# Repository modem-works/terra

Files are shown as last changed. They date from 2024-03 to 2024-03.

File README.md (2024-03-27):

<h1 align="center">TERRA is a companion for mindful wandering</h1>

<br> <!-- Additional spacing -->
<br> <!-- Additional spacing -->

<p align="center">
  TERRA Device
</p>

<br> <!-- Additional spacing -->
<br> <!-- Additional spacing -->

##  Designed with the science of AI and the wisdom of mindfulness, TERRA is the incredible, pocket-sized compass that lets you wander without getting lost. Leave your phone behind and reconnect with your surroundings.

<br> <!-- Additional spacing -->

### Features
- **Improvised Trails, Powered by AI**: Every journey begins with a prompt. TERRA’s sophisticated AI translates your intentions, available time, and precise location into a tailored trail of GPS coordinates. Users don't know where TERRA will take them; the only certainty is finding their way back to the starting point.
- **Wander Without Your Phone**: TERRA invites users to leave their smartphones behind and reconnect with their surroundings. The standalone device boasts a minimalist interface, featuring a tranquil compass needle and gentle haptic feedback to ensure users remain engaged with the present moment.  
- **Open-Source by Design**: TERRA is designed with a DIY mindset. Anyone can download the open-source software, 3D print the CAD designs, assemble the necessary hardware, and start wandering.

<br> <!-- Additional spacing -->

<p align="center">
  ⚠️ <strong>NOTICE</strong>: This project is currently in an experimental phase and is undergoing rapid developments ⚠️
</p>

<br> <!-- Additional spacing -->

### Software

The TERRA App generates coordinates or checkpoints from a starting point and an ideal trail length using the ChatGPT API.

### Running TERRA App Locally

#### Prerequisites 
- `Node.js` v21.5
- `body-parser` v1.20.2
- `cors` v2.8.5
- `express` v4.19.0
- `node-fetch` v3.3.2

To run the TERRA App locally, follow these steps:

1. **Implement ChatGPT API Key:** Obtain a [ChatGPT API key](https://platform.openai.com/) and replace ```YOUR_OPENAI_API_KEY``` with it in the ```server.js``` file.
2. **Implement Google Maps API Key:** Obtain a [Google Places API key](https://developers.google.com/maps/documentation/places/web-service/overview) and replace ```YOUR_MAPS_KEY``` with it in the ```index.js``` file.
3. **Run Locally:** To run the application, use the command:
    ```
    node server.js
    ```
4. **Load Application:** Open `index.html` in a browser to use the app for generating a route.
5. **Download config.h File:** Download the `config.h` file which contains the generated route configuration.
6. **Update Arduino Code:** Replace the `config.h` file in the Arduino code directory with the newly downloaded file.

### Hardware

The hardware for the TERRA project is based on an ESP32 device, equipped with a range of sensors for navigation and interaction.

### Components

The main components required are:

- ESP32 Feather V2 [link](https://learn.adafruit.com/adafruit-esp32-feather-v2/pinouts)
- Waveshare 1.28" Round LCD Display Module with GC9A01 Driver [link](https://www.waveshare.com/1.28inch-lcd-module.htm)
- Adafruit Push-button Power Switch [link](https://thepihut.com/products/adafruit-push-button-power-switch-breakout)
- Beitian BN 880 GPS module [link](https://store.beitian.com/products/beitian-compass-qmc5883l-amp2-6-pix4-pixhawk-gnss-gps-glonass-dual-flight-control-gps-module-bn-880q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)
- Adafruit DRV2605L Haptic Controller Breakout [link](https://learn.adafruit.com/adafruit-drv2605-haptic-controller-breakout/arduino-code)
- CMPS12 Compass [link](https://www.robot-electronics.co.uk/cmps12-tilt-compensated-magnetic-compass.html)
- Round Battery
- USB C charging port extender

### Wiring
Connect the components together in the following order:

| ESP32 Pin | Screen | Motor Driver | Compass | GPS | Push Button |
| --- | --- | --- | --- | --- | --- |
| 3V | VCC | VIN | VIN | VIN | |
| GND | GND | GND | GND | GND | GND |
| 19 (MOSI) | DIN | | | | |
| 4 (A5) | RST | | | | |
| 5 (SCK) | CLK | | | | |
| 12 | BL | | | | |
| 15 | CS | | | | |
| 32 (A7) | | | | | OFF |
| 33 | DC | | | | |
| SDA | | SDA | SDA | | |
| SCL | | SCL | SCL | | |
| RX | | | | TX  | |
| TX | | | | RX  | |

## Arduino Code

To run the Arduino code, you will need to set up the ESP32 board and install the necessary libraries.

### Setup Steps

1. **ESP32 Arduino Setup:** Add the ESP32 board to the Arduino IDE.
    - Go to **Arduino > Preferences**.
    - Add the following URL to the **Additional Boards Manager URLs**:
      ```
      https://raw.githubusercontent.com/espressif/arduino-esp32/gh-pages/package_esp32_dev_index.json
      ```
    - Select **Adafruit Feather ESP32 V2** as the board.

2. **Install Libraries:** Install the following libraries through the Library Manager in the Arduino IDE.
    - `TinyGPSPlus.h`
    - `TFT_eSPI.h`
    - `Adafruit_DRV2605.h`

3. **Upload the Code:** After installing the libraries and updating the `config.h` file with new coordinates, upload the code to the ESP32 device. The device should work without further adjustments.

4. **Debug Mode:** A `debugMode` flag is available in the code. To test the device with manual coordinates, set this flag to `true` and input coordinates into the serial monitor.

### Further Customizations

You can use your own checkpoint files by converting black and white images into a compatible format.

#### Using Your Own Checkpoint Files

- Convert static black and white, 240x240PX `.bmp` images to `.XBM` format using [this online tool](https://www.online-utility.org/image/convert/to/XBM).
- Open the XBM file in a text editor and copy the hexadecimal values included in the curly brackets.
- Replace the existing files in the `images/checkpoints` directory with your customized `.h` file.

### Contributors
Vision + Concept: Modem<br> 
Industrial Design: Panter&Tourron<br> 
Software + Hardware: Alice Stewart<br> 
Product Renderings: Côme Lart<br> 
Illustrations: Hugo Bernier<br> 
Campaign Teaser: Michael Willis

### License
TERRA is licensed under the GNU General Public License v3.0 © 2024 Modem

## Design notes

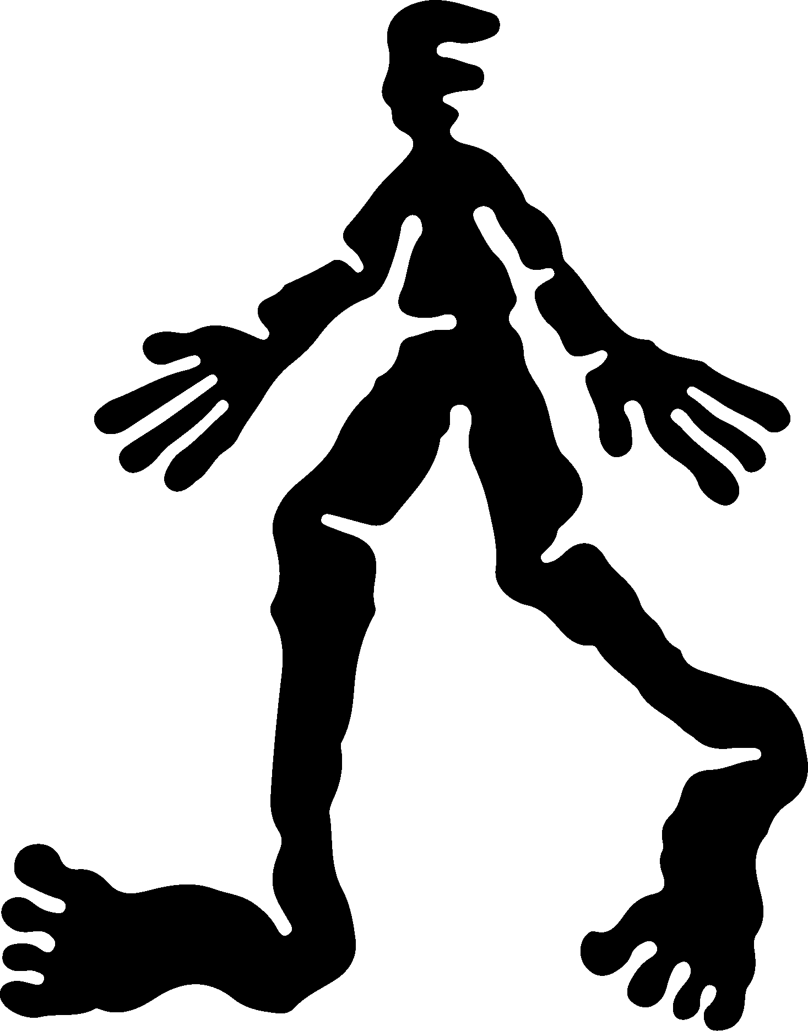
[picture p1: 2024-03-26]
App/walk.png

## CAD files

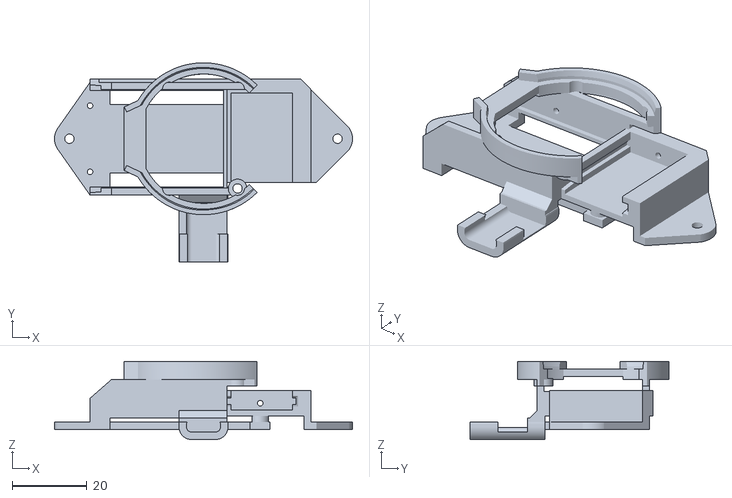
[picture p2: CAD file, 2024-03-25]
STL Files/TERRA_SKELETON_SLS_TOP.stl
80.0 x 53.5 x 21.0

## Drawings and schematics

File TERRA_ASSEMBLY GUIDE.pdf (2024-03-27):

## TERRA HARDWARE LIST

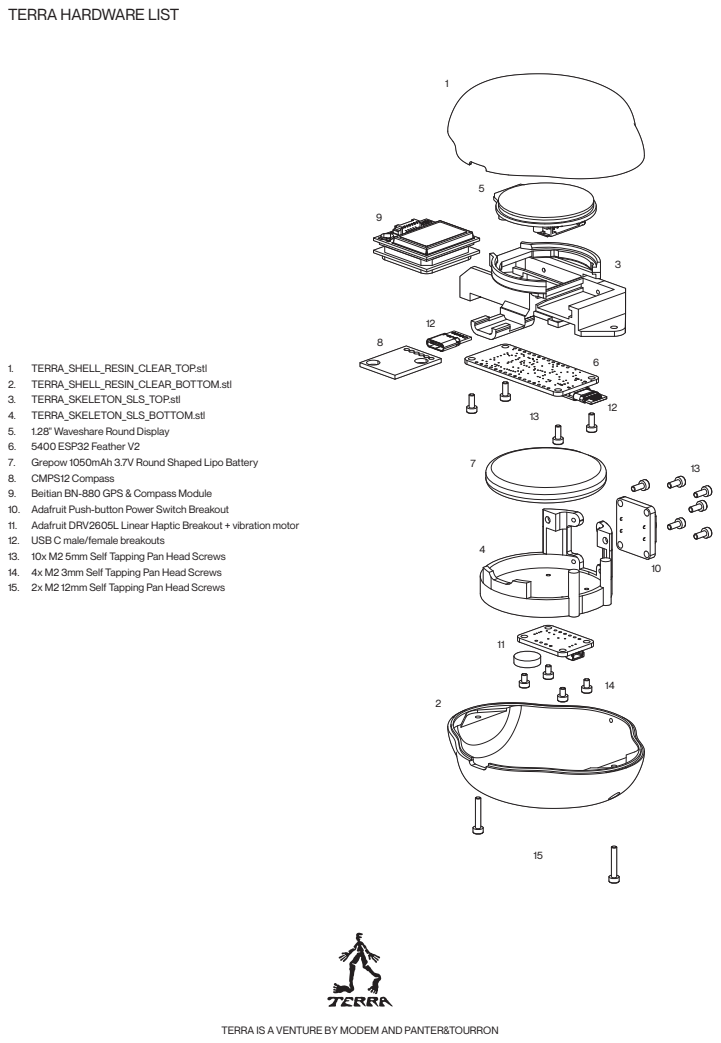
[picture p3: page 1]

1. TERRA_SHELL_RESIN_CLEAR_TOP.stl
2. TERRA_SHELL_RESIN_CLEAR_BOTTOM.stl
3. TERRA_SKELETON_SLS_TOP.stl
4. TERRA_SKELETON_SLS_BOTTOM.stl
5. 1.28" Waveshare Round Display
6. 5400 ESP32 Feather V2
7. Grepow 1050mAh 3.7V Round Shaped Lipo Battery
8. CMPS12 Compass
9. Beitian BN-880 GPS & Compass Module
10. Adafruit Push-button Power Switch Breakout
11. Adafruit DRV2605L Linear Haptic Breakout + vibration motor
12. USB C male/female breakouts
13. 10x M2 5mm Self Tapping Pan Head Screws
14. 4x M2 3mm Self Tapping Pan Head Screws
15. 2x M2 12mm Self Tapping Pan Head Screws

TERRA IS A VENTURE BY MODEM AND PANTER&TOURRON

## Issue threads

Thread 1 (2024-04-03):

Assembly Guide -> add an illustration about the wiring

mamatdunet, 2024-04-03:
Hi,

Amazing project ! Beyond the exploding view, do you plan to add a soldering / wiring illustration on the assembly guide
please (https://github.com/modem-works/terra/blob/main/TERRA_ASSEMBLY%20GUIDE.pdf) ?

https://fritzing.org/ is really good for that :).

Thank you :)

modem-works, 2024-04-05:
Hey!

Really appreciate you getting in touch and your kind feedback on the project!
Love the suggestion you shared. We’re definitely giving it some thought and will chat with our development team about it.

Best,
Fanneke

{–}

Modem
Office for Innovation and Design
@modem.works <https://instagram.com/modem.works>
modemworks.com <https://modemworks.com/>

© All rights reserved. This email and any attachments are
confidential and protected under international intellectual property
laws. If this email is not addressed to you, please delete this
email and its attachments and please be so kind to inform us.

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

mamatdunet, 2024-04-14:
Cool, thank you !

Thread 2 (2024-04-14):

Details missing from assembly guide

therealmoss, 2024-04-14:
Hello, I've been enjoying starting to build my own terra device.

Below are some details missing from the readme that I think are extremely important to add to help people get going without too much friction.

----------------------

1. **Install correct board drivers if using Mac / PC**
I was unable to connect to my Feather32 until I had installed the correct drivers [as detailed here in the Adafruit documentation. ](https://arc.net/l/quote/vlohxiwo). I think it would be wise to add this into the 'Setup steps' section of the readme.

2. **Adjust `User_Setup.h` file for TFT_eSPI library**
This one really caused me a lot of headaches. I spent many hours trying to figure out how to get the display to run _(I've only lightly dabbled in this sort of prototyping before)_!!!

3. Finally, I stumbled across [this video](https://youtu.be/k2c2zCmC_X0?si=9jiX2Kay5Wvr1BB6&t=1219), which explains how you must edit the `User_Setup.h` file in the display driver library. This finally got the display up and running for me. [Here is my own edited version of the file with the correct code changes to make the display run.](https://github.com/modem-works/terra/files/14972375/User_Setup.h.zip) Perhaps this could be included in the repo files, along with adding explicit instructions on doing this into the 'Install Libraries' step in the Arduino Code section?

3. **Add haptic motor to parts list**
You include the breakout in the parts list, but not the motor, as listed in the Assembly Guide PDF. I didn't purchase this initially, so this would be helpful to add, along with a link to an example part.

WannabeSpaceman, 2024-06-10:
I'm very glad you opened up this issue, because I'd been banging my head against a wall regarding the TFT_eSPI config issue for days now!

While the assembly instructions make sense once you've got the hardware in front of you, the setup sets could do with a lil more work

therealmoss, 2024-06-10:
I'm glad it was helpful @WannabeSpaceman !

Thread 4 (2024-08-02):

The documentation needs a demo video

Moth-6, 2024-08-02:
If anyone has built this can you share a video of the device and maybe a demo of how it works in real life?

oowze, 2024-08-04:
Looking through some of the threads on here, there seems to be a multitude of problems within the code and as of the 4th of August 2024 (5 months from it's initial release date), modem works has yet to update anything. At this point, TERRA seems to be a mere concept, I wouldn't be surprised if MW even was able to get TERRA working and in the wild.

For MW it's simply not profitable for the company to work on TERRA anymore, as a think tank modemworks has new projects to be working on and simply can't afford to spend anymore time to develop this product, there is no value in an opensource design for them. It's deflating to see such an innovative device be restricted because modemworks simply can't give a fu*k.

therealmoss, 2024-08-05:
Great idea!

therealmoss, 2024-08-22:
I'm still working on my build sporadically, but certainly no further development is happening from @modem-works

I will aim to do a demo video once I get the code working more effectively.

andrekochem, 2024-08-22:
Awesome, will love to see the further development

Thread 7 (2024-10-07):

SOS. HELP. I MUST HAVE ONE.  BLESSINS

TLALOC305, 2024-10-07:
__I have been researching this since meeting the new ram of LOVE-CAMP AT Burning Man.   I will fly wherever you are and learn how to build my own and trade you something of mine.  I will offer you and your loved ones eternal blessings and offer to be your spiritual guid in return.  René **_**_

kizeesmack, 2024-11-07:
I am currently building one and I'll let you know if its a success, its much easier in theory. theres a few hiccups that I've found!

TLALOC305, 2024-11-08:
Why don’t they sell them pre specd? Whats the  purpose if no one can’t make it Sent from my iPhoneOn Nov 7, 2024, at 2:13 AM, Kunal L. ***@***.***> wrote:
I am currently building one and I'll let you know if its a success, its much easier in theory. theres a few hiccups that I've found!

—Reply to this email directly, view it on GitHub, or unsubscribe.You are receiving this because you authored the thread.Message ID: ***@***.***>

coderolyat, 2024-11-13:
@kizeesmack hows it going I plan on making one what issues have you ran into?

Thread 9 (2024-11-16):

H

Asba3488, 2024-11-16:
11:52 O M O .
About
BBVA
App version 24.90.00
Android Operating System
8.7 K/s
Operating system version Android 14
Device model FNE-NX9 Build/HONORFNE-NO9
l33

Asba3488, 2024-11-16:
Google pay
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

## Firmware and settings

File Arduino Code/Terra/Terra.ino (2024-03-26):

// Latest working code as of March 26 2024.

bool debugMode = true;

// Include Libraries
#include <TinyGPSPlus.h>
#include <TFT_eSPI.h>
#include <Wire.h>
#include <map>
#include "Adafruit_DRV2605.h"

// Include Configurations and Images
#include "config.h"     // Assumes this contains GPS waypoints and number of stops
#include "imagelist.h"  // Assumes this includes declarations for images

// Sensor and Display Setup
#define CMPS12_ADDRESS 0x60
#define ANGLE_8 1
unsigned char high_byte, low_byte, angle8;
char pitch, roll;
unsigned int angle16;
#define BACKLIGHT_PIN 12

// TFT Display Settings
#define logoWidth 240
#define logoHeight 240
TFT_eSPI tft = TFT_eSPI();

// The TinyGPSPlus object
TinyGPSPlus gps;

// Vibration motor
Adafruit_DRV2605 drv;
int effectNumber = 58;
bool proximityVibrationTriggered = false;

// Thresholds for triggers in meters
int checkpointTrigger = 10;  // Distance from the checkpoint that is considered an arrival
int vibrationTrigger = 20;   // When to trigger vibration to indicate the checkpoint is getting close

unsigned long lastVibrationTime = 0;   // Tracks the last time vibration was triggered
int proximityVibrationDelayMs = 500;   // To determine the time between vibrations when close to the current stop.

// Image Types Enum
enum ImageType {
  NONE,
  PENDING,
  GOTOSTART,
  ARROW_N,
  ARROW_NNE,
  ARROW_NE,
  ARROW_ENE,
  ARROW_E,
  ARROW_ESE,
  ARROW_SE,
  ARROW_SSE,
  ARROW_S,
  ARROW_SSW,
  ARROW_SW,
  ARROW_WSW,
  ARROW_W,
  ARROW_WNW,
  ARROW_NW,
  ARROW_NNW,
  CHECKPOINT_1,
  CHECKPOINT_2,
  CHECKPOINT_3,
  CHECKPOINT_4,
  CHECKPOINT_5,
  CHECKPOINT_6,
  CHECKPOINT_7,
  CHECKPOINT_8,
  CHECKPOINT_9,
  CHECKPOINT_10
};
ImageType currentDisplayedImage = NONE;

enum NavigationState {
  NOT_STARTED,
  NAVIGATING,
  AT_CHECKPOINT,
  TRAIL_ENDED
};

// Initialize your navigation state
NavigationState navigationState = NOT_STARTED;  // Initial navigation state
unsigned long lastCheckpointTime = 0;           // Timestamp of when the last checkpoint was reached

// Global Variables for GPS Data and State
int currentStop = 0;
double currentLat, currentLon;
bool trailStarted = false;
bool dataReceived = false;
bool screenOn = false;
double distance;  // Distance to the next checkpoint

// Function Prototypes
void setup();
void loop();
void handleGPSData();
bool readSerialGPS();
bool readGPS();
void determineTrailStatusAndNavigate();
void processGPSData(double lat, double lon);
bool nonBlockingDelay(unsigned long ms);
void displayImage(ImageType image);
void fadeOut();
void fadeIn();
double getDistanceTo(double lat, double lon);
String getCardinalTo(double lat, double lon);
int getCourseTo(double lat, double lon);
int readCompass();

// Setup Function
void setup() {
  Serial.begin(115200);

  if (!debugMode) {
    Serial1.begin(9600);
  }

  // Screen
  tft.init();
  tft.setRotation(1);
  pinMode(BACKLIGHT_PIN, OUTPUT);
  digitalWrite(BACKLIGHT_PIN, LOW);


  // Vibration motor
  if (!drv.begin()) {
    Serial.println("Could not find DRV2605");
    while (1) delay(10);
  }

  drv.selectLibrary(1);
  // I2C trigger by sending 'go' command
  // default, internal trigger when sending GO command
  drv.setMode(DRV2605_MODE_INTTRIG);

  Wire.begin();
}

// Main Loop
void loop() {
  if (nonBlockingDelay(1000)) {
    handleGPSData();
    determineTrailStatusAndNavigate();
  }
  if (!debugMode) {
    smartDelay(1000);  // for reading the GPS module
  }
  // Continuously trigger vibration when within a certain distance of the next stop
  if (proximityVibrationTriggered && millis() - lastVibrationTime >= proximityVibrationDelayMs) {
    triggerProximityVibration();
    lastVibrationTime = millis();  // Update the last vibration time
  }
}

// This custom version of delay() ensures that the gps object is being "fed".
static void smartDelay(unsigned long ms) {
  unsigned long start = millis();
  do {
    while (Serial1.available())
      gps.encode(Serial1.read());
  } while (millis() - start < ms);
}

// Handle GPS Data
void handleGPSData() {
  if (debugMode) {  // If we're in debug mode, read the serial input
    if (Serial.available()) {
      if (readSerialGPS()) {
        dataReceived = true;  // Once the first data has arrived, we can get into our start routine
      }
    }
  } else {  // If we're not in serial input mode, start handling real GPS data
    while (Serial1.available()) {
      if (readGPS()) {
        dataReceived = true;
      }
    }
  }
}

// Read the GPS signal for current lat/lon - this is a serial input for now but can be replaced with code to read the GPS module
bool readSerialGPS() {
  String inputString = Serial.readStringUntil('\n');
  int commaIndex = inputString.indexOf(',');

  // Check if the comma exists and it's not at the end of the string
  if (commaIndex != -1 && commaIndex < inputString.length() - 1) {
    currentLat = inputString.substring(0, commaIndex).toDouble();
    currentLon = inputString.substring(commaIndex + 1).toDouble();
    return true;  // Data was successfully parsed
  } else {
    Serial.println("Invalid format. Please enter in format: lat,lon");
    return false;  // Data parsing failed
  }
}

// Read the GPS module signal for current lat/lon
bool readGPS() {
  if (gps.location.isValid()) {
    currentLat = gps.location.lat();
    currentLon = gps.location.lng();
    return true;
  }
  return false;
}

void determineTrailStatusAndNavigate() {
  static double lastDistance = -1;

  // Obtain the target coordinates based on the trail's current status
  double targetLat = !trailStarted ? startLat : stopLats[currentStop - 1];
  double targetLon = !trailStarted ? startLon : stopLons[currentStop - 1];

  // Calculate the current distance and direction to the target
  double distance = getDistanceTo(targetLat, targetLon);
  String cardinal = getCardinalTo(targetLat, targetLon);
  int targetAngle = getCourseTo(targetLat, targetLon);  // Assume implementation exists
  int currentAngle = readCompass();

  // Calculate the relative direction for navigation
  int relativeDirection = calculateRelativeDirection(currentAngle, targetAngle);

  if (navigationState == NOT_STARTED) {
    if (!dataReceived) {
      displayImage(PENDING);  // Show PENDING only when waiting for the first GPS data
    } else {
      Serial.println("Please proceed to the start of the trail.");
      displayImage(GOTOSTART);  // Now we're sure we've received data, show GOTOSTART
    }

    // Transition to navigating state once within close range to the start and data has been received
    if (dataReceived && distance <= checkpointTrigger) {
      trailStarted = true;
      currentStop = 1;
      Serial.println("Trail started. Heading to Stop 1.");
      navigationState = NAVIGATING;
    }
    return;  // Continue to skip rest of the function logic when NOT_STARTED
  }

  // Only update navigation arrow if we are in the navigating phase
  if (navigationState == NAVIGATING) {
    ImageType arrowImage = selectArrowImage(relativeDirection);
    displayImage(arrowImage);
  }

  // Start of the trail
  if (!trailStarted) {
    if (distance <= checkpointTrigger) {  // "Closeness" threshold
      trailStarted = true;
      currentStop = 1;  // Moving towards the first checkpoint
      Serial.println("Trail started. Heading to Stop 1.");
      navigationState = NAVIGATING;
    } else {
      Serial.println("Please proceed to the start of the trail.");
      if (dataReceived) {
        displayImage(GOTOSTART);  // Indicating to go to the starting point
      }
    }
  }
  // Navigating the trail
  else {
    if (distance <= checkpointTrigger && currentStop <= numberOfStops) {
      if (navigationState != AT_CHECKPOINT) {
        // Just arrived at this checkpoint
        Serial.print("Arrived at Stop ");
        Serial.println(currentStop);
        ImageType checkpointImage = static_cast<ImageType>(CHECKPOINT_1 + currentStop - 1);
        displayImage(checkpointImage);    // Show the checkpoint image
        navigationState = AT_CHECKPOINT;  // Update state to at checkpoint
        lastCheckpointTime = millis();    // Capture the time we arrived at the checkpoint

        // Check if this is the final stop
        if (currentStop == numberOfStops) {
          Serial.println("Final stop reached. Trail is complete.");
          // Display PENDING image to indicate completion
          displayImage(PENDING);
          // Optionally, you might want to change the navigation state or take other actions here
          navigationState = TRAIL_ENDED;  // Resetting the state to NOT_STARTED or another appropriate state
        }

        proximityVibrationTriggered = false;  // Allow vibration to trigger again for the next stop
        currentStop++;                        // Prepare for the next stop or complete the trail
      }
    } else if (navigationState == AT_CHECKPOINT) {
      if (millis() - lastCheckpointTime > 5000) {  // 5 seconds have passed since arriving at the checkpoint
        navigationState = NAVIGATING;              // Transition back to navigating after the delay
        proximityVibrationTriggered = false;       // Reset vibration trigger flag
      }
    } else if (navigationState == NAVIGATING && currentStop <= numberOfStops) {
      // Continue with the condition to update navigation info only if there's a significant change in distance
      if (abs(lastDistance - distance) > 0.5) {
        Serial.print("Distance to next stop: ");
        Serial.print(distance, 1);  // One decimal place for distance
        Serial.print(" meters. Direction to next stop: ");
        Serial.print(cardinal);
        Serial.print(" (Target angle: ");
        Serial.print(targetAngle);
        Serial.println(" degrees)");
        lastDistance = distance;  // Update lastDistance for next comparison

        // Here, potentially display the arrow again if needed, based on your logic for selecting and displaying arrows
        ImageType arrowImage = selectArrowImage(relativeDirection);
        displayImage(arrowImage);

        // Set the flag to start continuous vibration when within a certain distance from the next stop
        if (distance <= vibrationTrigger && !proximityVibrationTriggered) {
          proximityVibrationTriggered = true;
          lastVibrationTime = millis();  // Ensure we start timing from now
        }
      }
    }
  }
}

void triggerProximityVibration() {
  // Check if we should still be vibrating (if within a certain distance and navigating)
  if (distance <= proximityVibrationTriggered && navigationState == NAVIGATING) {
    // set the effect to play
    drv.setWaveform(0, effectNumber);  // play effect
    drv.setWaveform(1, 0);             // end waveform
    // play the effect!
    drv.go();
    // Serial.println("Vibration triggered");
    // Note: We do not set vibrationTriggered to false here as we want continuous vibration
  } else {
    // Stop vibrating if no longer within 20 meters or not in navigating state
    proximityVibrationTriggered = false;
  }
}

// Display image function - fades images out then in again
void displayImage(ImageType image) {
  if (currentDisplayedImage != image) {
    if (screenOn) {
      fadeOut();
    }
    tft.fillScreen(TFT_BLACK);  // This line is common to all cases
    switch (image) {
      case PENDING:
        drawBitmap(pending);
        Serial.println("Drawn pending.h");
        break;
      case GOTOSTART:
        drawBitmap(gotostart);
        Serial.println("Drawn gotostart.h");
        break;
      case ARROW_N:
        drawBitmap(arrow_N);
        Serial.println("Drawn arrow_N.h");
        break;
      case ARROW_NNE:
        drawBitmap(arrow_NNE);
        Serial.println("Drawn arrow_NNE.h");
        break;
      case ARROW_NE:
        drawBitmap(arrow_NE);
        Serial.println("Drawn arrow_NE.h");
        break;
      case ARROW_ENE:
        drawBitmap(arrow_ENE);
        Serial.println("Drawn arrow_ENE.h");
        break;
      case ARROW_E:
        drawBitmap(arrow_E);
        Serial.println("Drawn arrow_E.h");
        break;
      case ARROW_ESE:
        drawBitmap(arrow_ESE);
        Serial.println("Drawn arrow_ESE.h");
        break;
      case ARROW_SE:
        drawBitmap(arrow_SE);
        Serial.println("Drawn arrow_SE.h");
        break;
      case ARROW_SSE:
        drawBitmap(arrow_SSE);
        Serial.println("Drawn arrow_SSE.h");
        break;
      case ARROW_S:
        drawBitmap(arrow_S);
        Serial.println("Drawn arrow_S.h");
        break;
      case ARROW_SSW:
        drawBitmap(arrow_SSW);
        Serial.println("Drawn arrow_SSW.h");
        break;
      case ARROW_SW:
        drawBitmap(arrow_SW);
        Serial.println("Drawn arrow_SW.h");
        break;
      case ARROW_WSW:
        drawBitmap(arrow_WSW);
        Serial.println("Drawn arrow_WSW.h");
        break;
      case ARROW_W:
        drawBitmap(arrow_W);
        Serial.println("Drawn arrow_W.h");
        break;
      case ARROW_WNW:
        drawBitmap(arrow_WNW);
        Serial.println("Drawn arrow_WNW.h");
        break;
      case ARROW_NW:
        drawBitmap(arrow_NW);
        Serial.println("Drawn arrow_NW.h");
        break;
      case ARROW_NNW:
        drawBitmap(arrow_NNW);
        Serial.println("Drawn arrow_NNW.h");
        break;
      case CHECKPOINT_1:
        drawBitmap(checkpoint_1);
        Serial.println("Drawn checkpoint_1.h");
        break;
      case CHECKPOINT_2:
        drawBitmap(checkpoint_2);
        Serial.println("Drawn checkpoint_2.h");
        break;
      case CHECKPOINT_3:
        drawBitmap(checkpoint_3);
        Serial.println("Drawn checkpoint_3.h");
        break;
      case CHECKPOINT_4:
        drawBitmap(checkpoint_4);
        Serial.println("Drawn checkpoint_4.h");
        break;
      case CHECKPOINT_5:
        drawBitmap(checkpoint_5);
        Serial.println("Drawn checkpoint_5.h");
        break;
      case CHECKPOINT_6:
        drawBitmap(checkpoint_6);
        Serial.println("Drawn checkpoint_6.h");
        break;
      case CHECKPOINT_7:
        drawBitmap(checkpoint_7);
        Serial.println("Drawn checkpoint_7.h");
        break;
      case CHECKPOINT_8:
        drawBitmap(checkpoint_8);
        Serial.println("Drawn checkpoint_8.h");
        break;
      case CHECKPOINT_9:
        drawBitmap(checkpoint_9);
        Serial.println("Drawn checkpoint_9.h");
        break;
      case CHECKPOINT_10:
        drawBitmap(checkpoint_10);
        Serial.println("Drawn checkpoint_10.h");
        break;
      default:
        tft.fillScreen(TFT_BLACK);
        Serial.println("No image to display");
    }
    fadeIn();
    currentDisplayedImage = image;
  }
}

void drawBitmap(const unsigned char* bitmap) {
  tft.drawXBitmap(0, 0, bitmap, logoWidth, logoHeight, TFT_BLACK, TFT_WHITE);
}

// Example function to calculate relative direction based on angles
int calculateRelativeDirection(int currentAngle, int targetAngle) {
  int difference = targetAngle - currentAngle;
  if (difference < 0) {
    difference += 360;  // Adjust for negative differences
  }
  return difference % 360;  // Ensure the result is within 0-359 degreess
}


// Select an arrow image based on relative direction
ImageType selectArrowImage(int relativeDirection) {
  if (relativeDirection >= 348.75 || relativeDirection < 11.25) return ARROW_N;
  else if (relativeDirection >= 11.25 && relativeDirection < 33.75) return ARROW_NNE;
  else if (relativeDirection >= 33.75 && relativeDirection < 56.25) return ARROW_NE;
  else if (relativeDirection >= 56.25 && relativeDirection < 78.75) return ARROW_ENE;
  else if (relativeDirection >= 78.75 && relativeDirection < 101.25) return ARROW_E;
  else if (relativeDirection >= 101.25 && relativeDirection < 123.75) return ARROW_ESE;
  else if (relativeDirection >= 123.75 && relativeDirection < 146.25) return ARROW_SE;
  else if (relativeDirection >= 146.25 && relativeDirection < 168.75) return ARROW_SSE;
  else if (relativeDirection >= 168.75 && relativeDirection < 191.25) return ARROW_S;
  else if (relativeDirection >= 191.25 && relativeDirection < 213.75) return ARROW_SSW;
  else if (relativeDirection >= 213.75 && relativeDirection < 236.25) return ARROW_SW;
  else if (relativeDirection >= 236.25 && relativeDirection < 258.75) return ARROW_WSW;
  else if (relativeDirection >= 258.75 && relativeDirection < 281.25) return ARROW_W;
  else if (relativeDirection >= 281.25 && relativeDirection < 303.75) return ARROW_WNW;
  else if (relativeDirection >= 303.75 && relativeDirection < 326.25) return ARROW_NW;
  else if (relativeDirection >= 326.25 && relativeDirection < 348.75) return ARROW_NNW;
  else return ARROW_N;  // Default case, although logically unnecessary due to the first condition
}

// Non blocking delay to read sensors
bool nonBlockingDelay(unsigned long ms) {
  static unsigned long lastCheck = 0;
  unsigned long currentMillis = millis();
  if (currentMillis - lastCheck >= ms) {
    lastCheck = currentMillis;
    return true;
  }
  return false;
}

// Simple function to get distance to lat/lon, is used to determine whether GPS module is in range of a stop
double getDistanceTo(double lat, double lon) {
  return TinyGPSPlus::distanceBetween(currentLat, currentLon, lat, lon);
}

String getCardinalTo(double lat, double lon) {
  double courseTo = TinyGPSPlus::courseTo(currentLat, currentLon, lat, lon);
  String cardinal = TinyGPSPlus::cardinal(courseTo);
  return cardinal;
}

int getCourseTo(double lat, double lon) {
  return TinyGPSPlus::courseTo(currentLat, currentLon, lat, lon);
}

// Read the compass sensor and return the compassDirection in cardinal points
int readCompass() {                        // is string if we're asking for cardinal.
  Wire.beginTransmission(CMPS12_ADDRESS);  // Starts communication with CMPS12
  Wire.write(ANGLE_8);                     // Sends the register we wish to start reading from
  Wire.endTransmission();

  // Request 5 bytes from the CMPS12
  // this will give us the 8 bit bearing,
  // both bytes of the 16 bit bearing, pitch and roll
  Wire.requestFrom(CMPS12_ADDRESS, 5);

  while (Wire.available() < 5)
    ;  // Wait for all bytes to come back

  angle8 = Wire.read();  // Read back the 5 bytes
  high_byte = Wire.read();
  low_byte = Wire.read();
  pitch = Wire.read();
  roll = Wire.read();

  angle16 = high_byte;  // Calculate 16 bit angle
  angle16 <<= 8;
  angle16 += low_byte;

  int currentAngle = angle16 / 10;
  return currentAngle;
}

void fadeOut() {
  for (int i = 255; i >= 0; i -= 5) {
    analogWrite(BACKLIGHT_PIN, i);
    delay(10);
  }
  screenOn = false;
}

void fadeIn() {
  for (int i = 0; i <= 255; i += 5) {
    analogWrite(BACKLIGHT_PIN, i);
    delay(10);
  }
  screenOn = true;
}

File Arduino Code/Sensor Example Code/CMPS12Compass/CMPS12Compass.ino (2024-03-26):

/* Working Example for  CMPS12 I2C Compass module. Code originally written by James Henderson, 2014.
Last edit: 23 Feb 2024.

This example code prints the sensor data (8 and 16 bit heading, magnetometer, accelerometer and gyro)

The example code has been modified to compensate for calibration with an iPhone compass.
When the sensor is lined up with a separate compass pointing North and the values do not match 0, 
the value displayed is input as the "offset" for calibration.

The cardinal directions have also been added as variables.

*/

#include <Wire.h>

#define CMPS12_ADDRESS 0x60  // Address of CMPS12 shifted right one bit for arduino wire library
#define ANGLE_8 1            // Register to read 8bit angle from

// Offset angle discovered during calibration between iPhone compass and the sensor.

// const int offset = 335;

unsigned char high_byte, low_byte, angle8;
char pitch, roll;
unsigned int angle16;

void setup() {
  Serial.begin(115200);  // Start serial port
  Wire.begin();
}

void loop() {

  Wire.beginTransmission(CMPS12_ADDRESS);  // Starts communication with CMPS12
  Wire.write(ANGLE_8);                     // Sends the register we wish to start reading from
  Wire.endTransmission();

  // Request 5 bytes from the CMPS12
  // this will give us the 8 bit bearing,
  // both bytes of the 16 bit bearing, pitch and roll
  Wire.requestFrom(CMPS12_ADDRESS, 5);

  while (Wire.available() < 5)
    ;  // Wait for all bytes to come back

  angle8 = Wire.read();  // Read back the 5 bytes
  high_byte = Wire.read();
  low_byte = Wire.read();
  pitch = Wire.read();
  roll = Wire.read();

  angle16 = high_byte;  // Calculate 16 bit angle
  angle16 <<= 8;
  angle16 += low_byte;

  Serial.print("roll: ");               // Display roll data
  Serial.print(roll, DEC);

  Serial.print("    pitch: ");          // Display pitch data
  Serial.print(pitch, DEC);

  Serial.print("    angle 8: ");        // Display 8bit angle
  Serial.print(angle8, DEC);

  Serial.print("    angle 16: ");     // Display 16 bit angle with decimal place
  Serial.print(angle16 / 10, DEC);
  Serial.print(".");
  Serial.print(angle16 % 10, DEC);

  // // Apply the offset and adjust for wrap-around
  // int calibratedAngle16 = (angle16 - (offset * 10) + 3600) % 3600;

  // // Display calibrated angle
  // Serial.print("    calibrated angle: ");
  // Serial.print(calibratedAngle16 / 10, DEC);
  // Serial.print(".");
  // Serial.print(calibratedAngle16 % 10, DEC);

  // Display cardinal direction 
  Serial.print("    cardinal direction: ");
  // Serial.println(getCardinalDirection(calibratedAngle16 / 10));
  Serial.println(getCardinalDirection(angle16 / 10));

  // delay for readibility
  delay (100);

}

String getCardinalDirection(int angle) {
    const String directions[] = {"N", "NNE", "NE", "ENE", "E", "ESE", "SE", "SSE",
                                 "S", "SSW", "SW", "WSW", "W", "WNW", "NW", "NNW"};

    // Divide the angle by 22.5 since each direction covers 22.5 degrees
    // Add 0.5 to handle rounding to the nearest direction
    int val = (int)((angle / 22.5) + 0.5);

    // Use modulus 16 to wrap around the array index
    return directions[val % 16];
}
